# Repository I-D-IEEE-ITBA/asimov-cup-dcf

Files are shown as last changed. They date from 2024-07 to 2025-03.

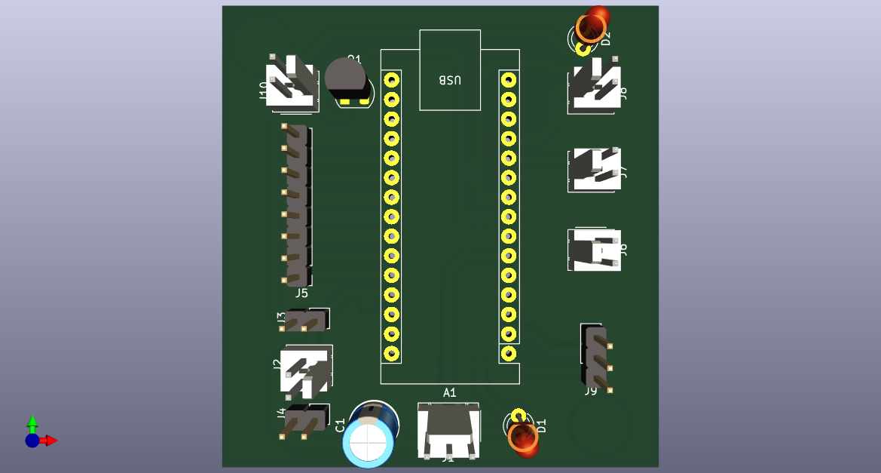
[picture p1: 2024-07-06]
docs/pcb_designs/controller/3d_top.png

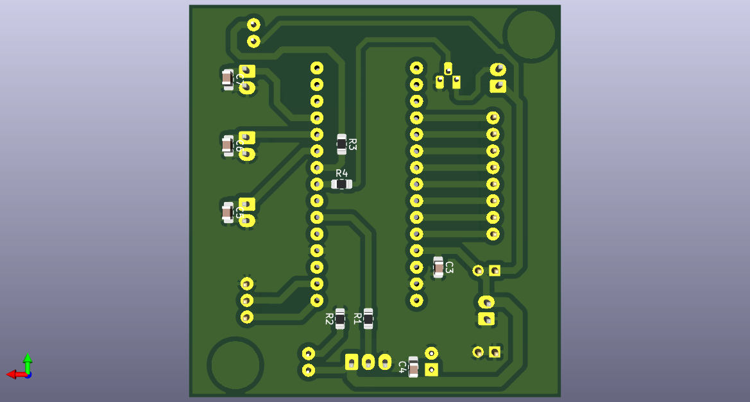
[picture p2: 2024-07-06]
docs/pcb_designs/controller/3d_bot.png

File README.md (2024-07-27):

# Display Contador Futbol (DCF)

## Descripción

Proyecto del *Display Contador Futbol*, que forma parte del desarrollo de la [Asimov Cup](https://ieeeitba.org.ar/asimovcup) en la competencia de *Futbol*.

DCF permite dar la señal de inicio del partido, cronometrar el tiempo de juego, pausarlo de ser necesario, a la vez que mantiene la cuenta de goles anotados por cada equipo.

El repositorio incluye tanto el hardware como el firmware desarrollado.

----------

<p align="middle">    
    ITBA Logo
    <a href="https://ieeeitba.org.ar/">IEEE ITBA Logo</a>
    IEEE Logo
</p>

<p align="middle">    
    <a href="https://github.com/IEEESBITBA">GitHub Repository</a>
    <a href="https://www.linkedin.com/company/ieee-itba/">LinkedIn Organization</a>
    <a href="https://www.instagram.com/ieee.itba/">Instagram Profile</a>
</p>

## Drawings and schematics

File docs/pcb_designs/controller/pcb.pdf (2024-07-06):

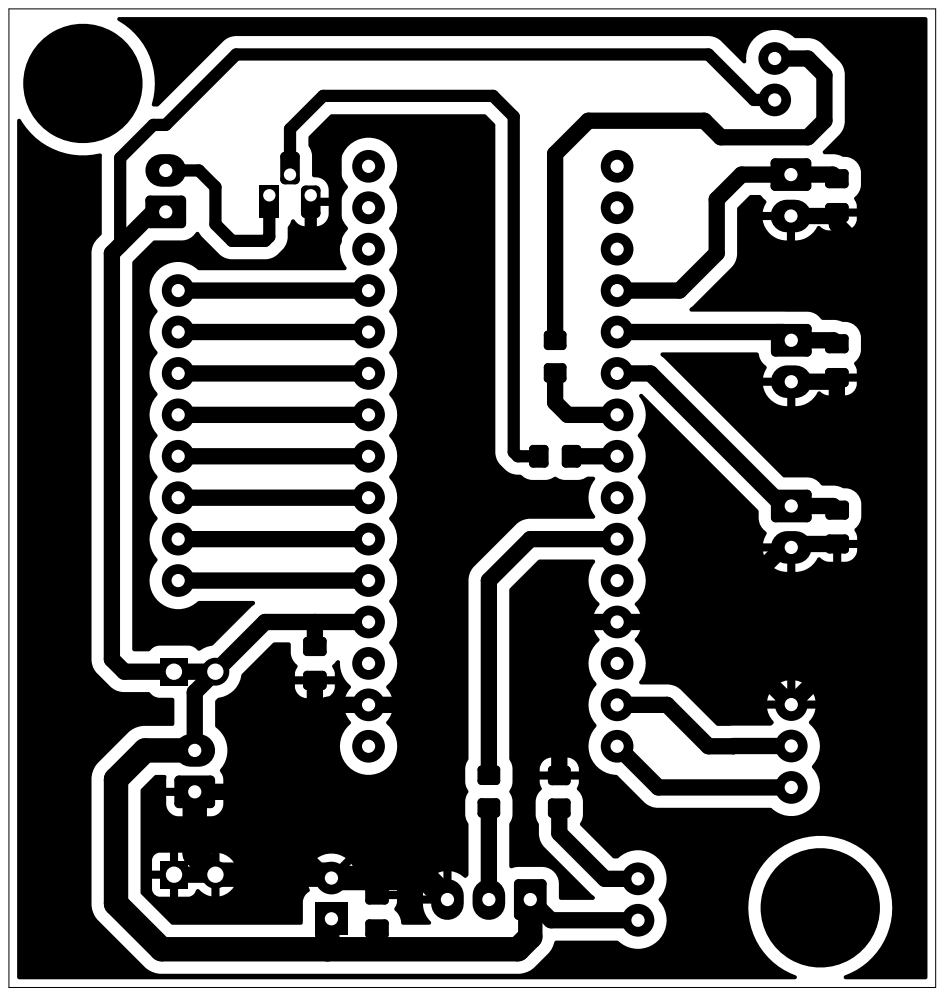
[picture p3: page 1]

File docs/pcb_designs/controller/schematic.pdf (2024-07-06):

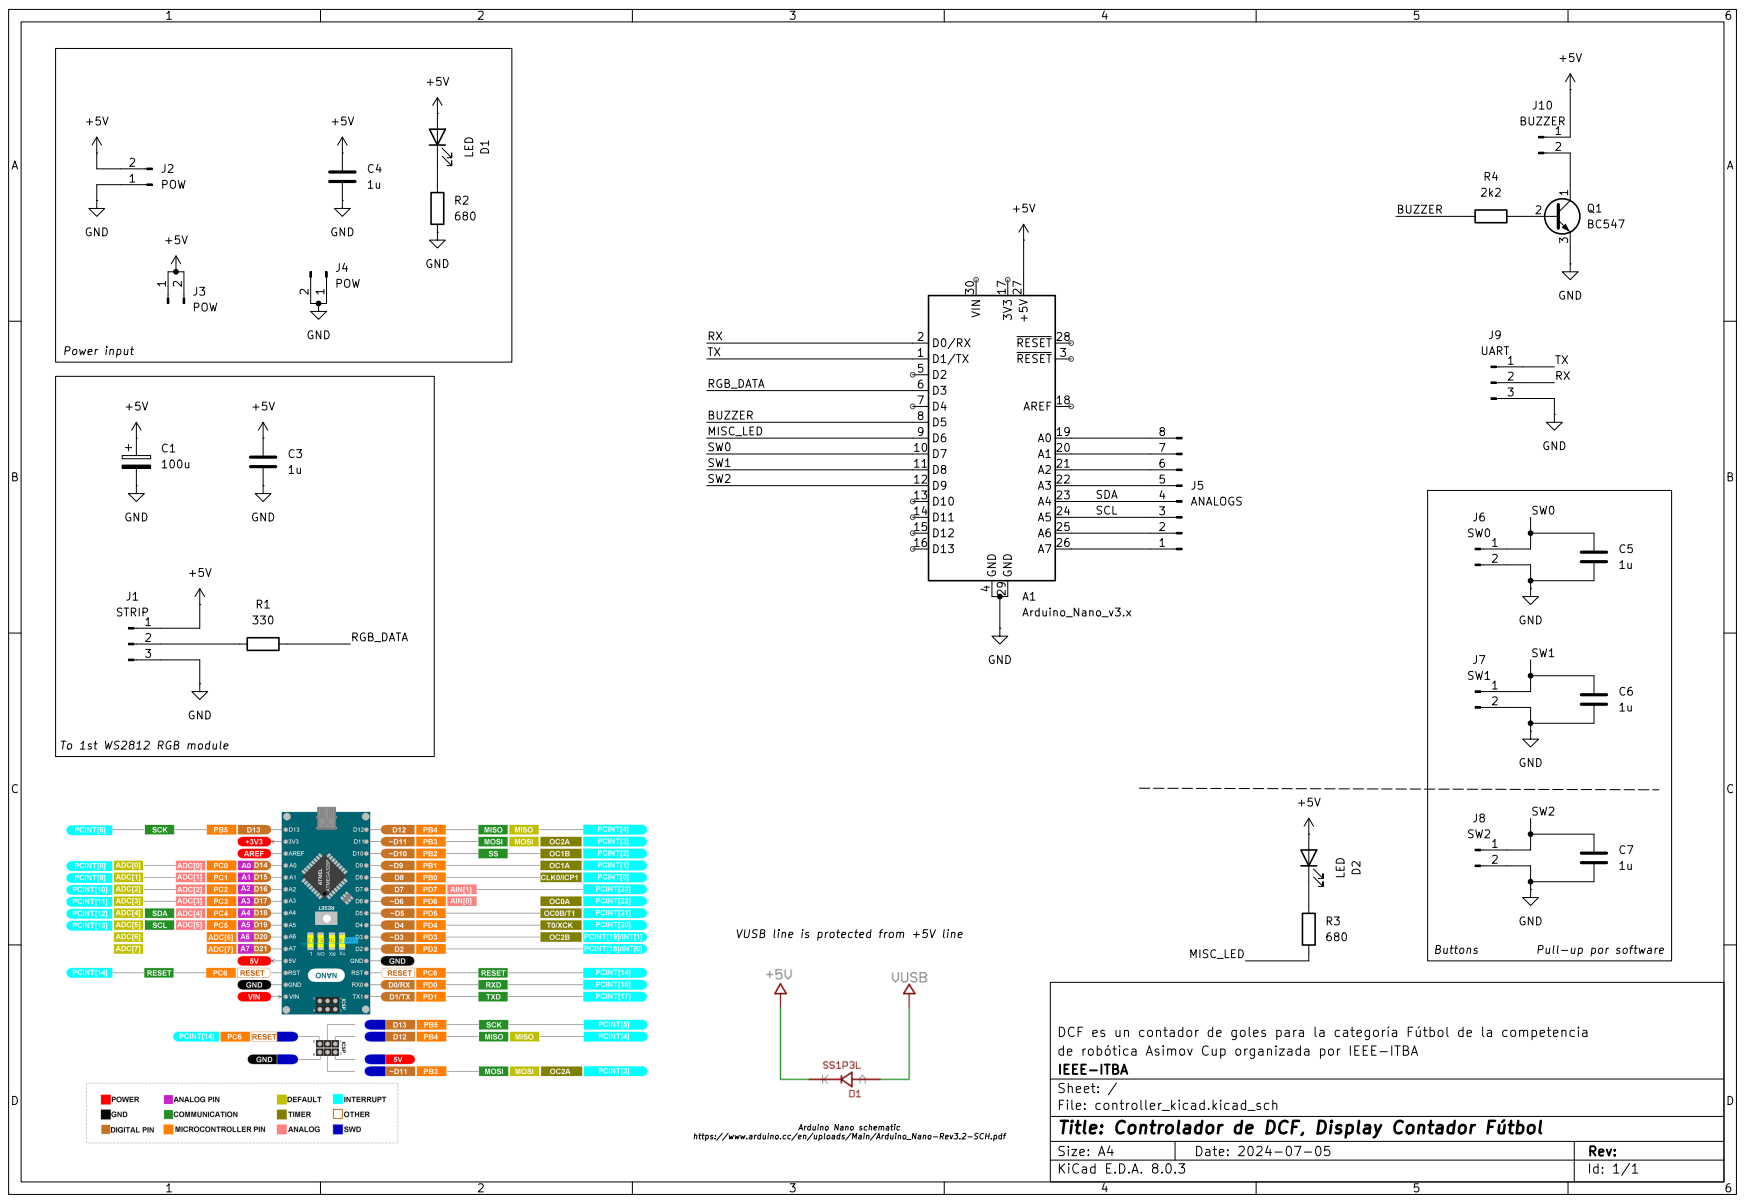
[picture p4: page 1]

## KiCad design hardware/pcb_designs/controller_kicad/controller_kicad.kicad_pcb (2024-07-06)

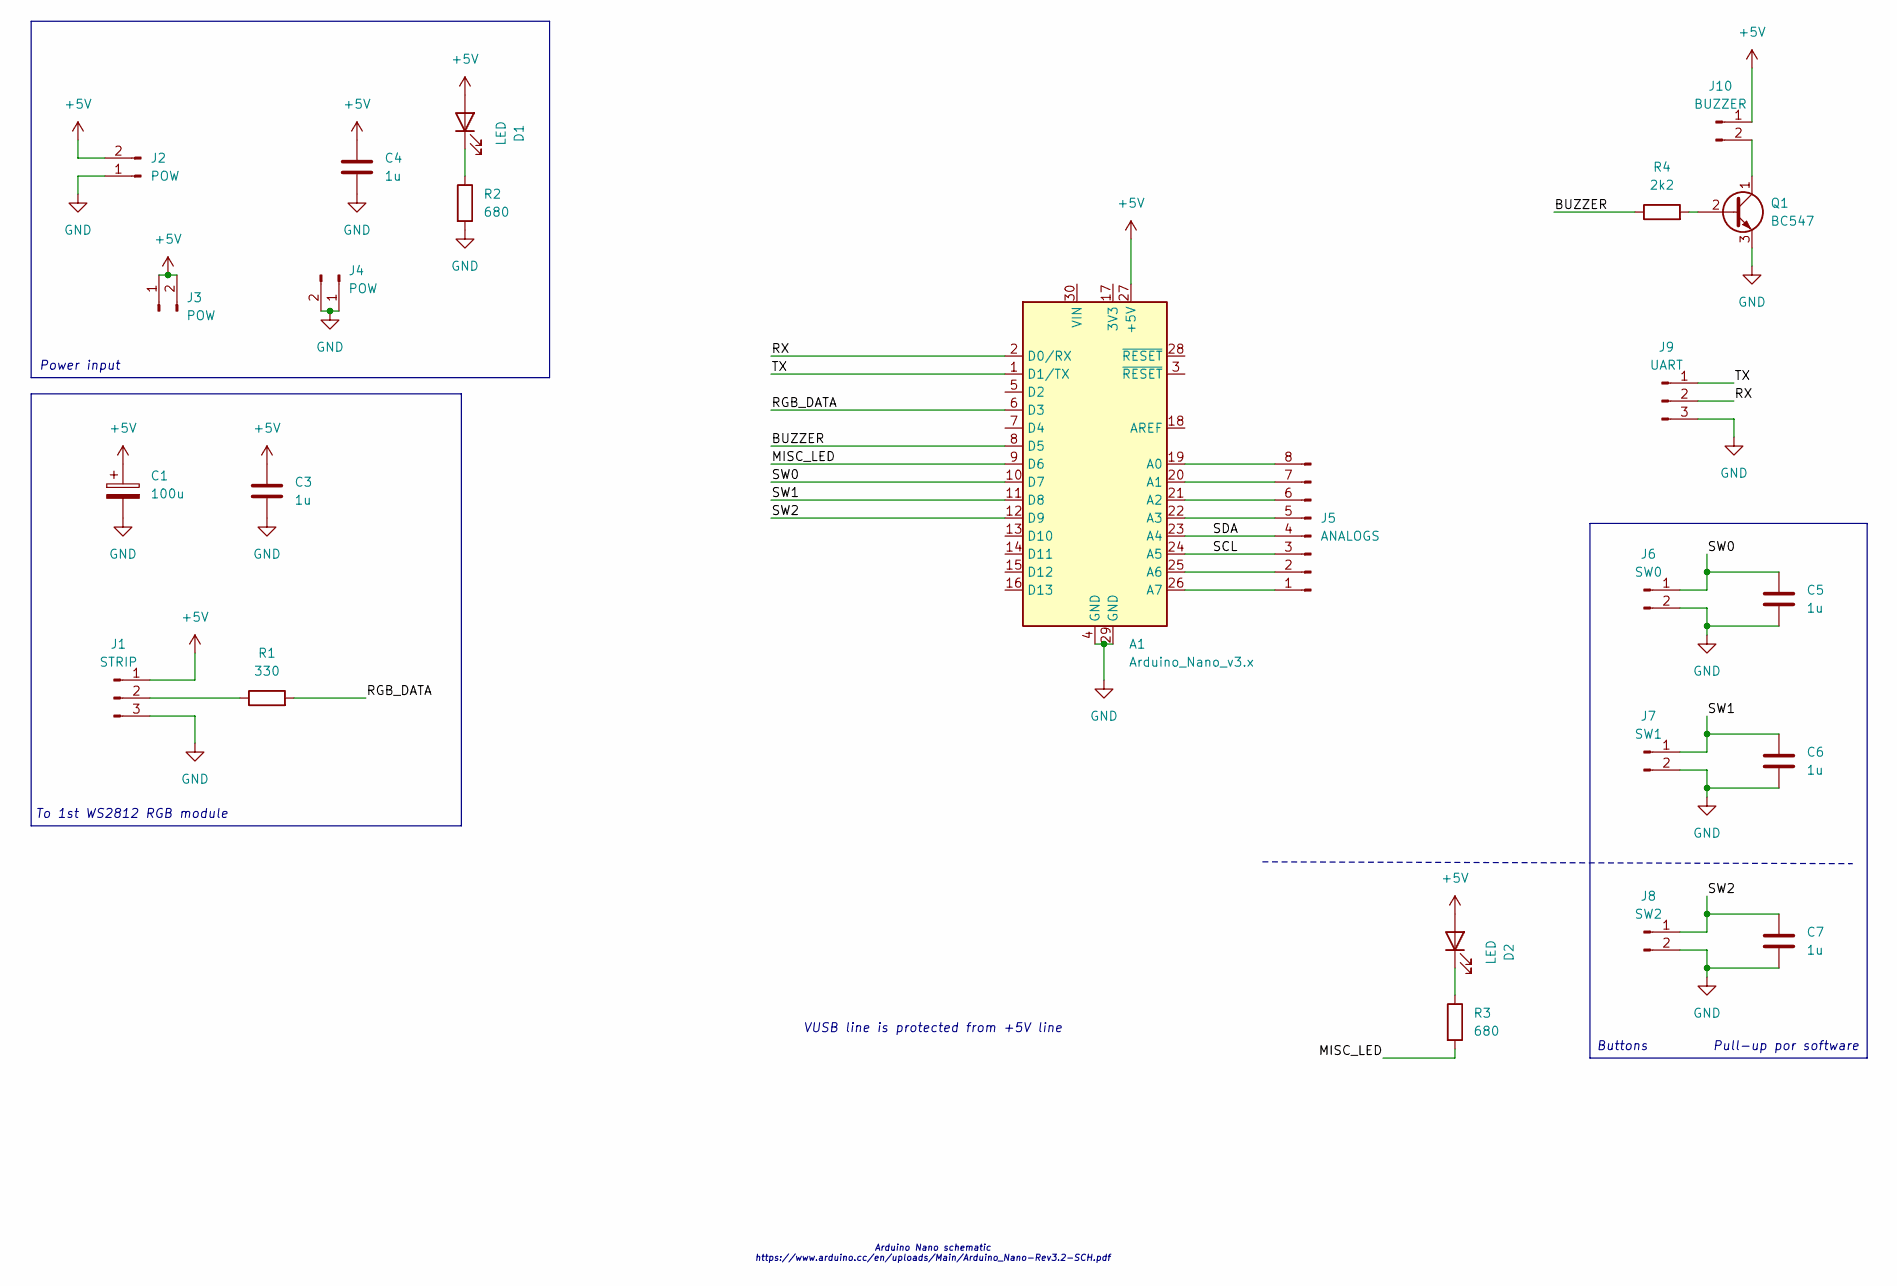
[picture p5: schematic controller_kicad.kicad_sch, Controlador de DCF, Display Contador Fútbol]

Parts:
A1: Arduino_Nano_v3.x; Arduino_Nano
C1: 100u; CP_Radial_D6.3mm_P2.50mm
C3, C4, C5, C6, C7: 1u; C_0805_2012Metric_Pad1.18x1.45mm_HandSolder
D1, D2: LED; LED_D3.0mm
J1: STRIP; Molex_KK-254_AE-6410-03A_1x03_P2.54mm_Vertical
J2: POW; Molex_KK-254_AE-6410-02A_1x02_P2.54mm_Vertical
J3, J4: POW; PinHeader_1x02_P2.54mm_Vertical
J5: ANALOGS; PinHeader_1x08_P2.54mm_Vertical
J6: SW0; Molex_KK-254_AE-6410-02A_1x02_P2.54mm_Vertical
J7: SW1; Molex_KK-254_AE-6410-02A_1x02_P2.54mm_Vertical
J8: SW2; Molex_KK-254_AE-6410-02A_1x02_P2.54mm_Vertical
J9: UART; PinHeader_1x03_P2.54mm_Vertical
J10: BUZZER; Molex_KK-254_AE-6410-02A_1x02_P2.54mm_Vertical
Q1: BC547; TO-92_HandSolder
R1: 330; R_0805_2012Metric_Pad1.20x1.40mm_HandSolder
R2, R3: 680; R_0805_2012Metric_Pad1.20x1.40mm_HandSolder
R4: 2k2; R_0805_2012Metric_Pad1.20x1.40mm_HandSolder

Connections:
+5V: A1.27 (+5V), C1.1, C3.1, C4.1, D1.2 (A), D2.2 (A), J1.1, J2.2, J3.1, J3.2, J10.1
/BUZZER: A1.8 (D5), R4.1
/MISC_LED: A1.9 (D6), R3.2
/RGB_DATA: A1.6 (D3), R1.2
/RX: A1.2 (D0/RX), J9.2
/SCL: A1.24 (A5), J5.3
/SDA: A1.23 (A4), J5.4
/SW0: A1.10 (D7), C5.1, J6.1
/SW1: A1.11 (D8), C6.1, J7.1
/SW2: A1.12 (D9), C7.1, J8.1
/TX: A1.1 (D1/TX), J9.1
GND: A1.4 (GND), A1.29 (GND), C1.2, C3.2, C4.2, C5.2, C6.2, C7.2, J1.3, J2.1, J4.1, J4.2, J6.2, J7.2, J8.2, J9.3, Q1.3 (E), R2.2
unnamed: A1.19 (A0), J5.8
unnamed: A1.20 (A1), J5.7
unnamed: A1.21 (A2), J5.6
unnamed: A1.22 (A3), J5.5
unnamed: A1.25 (A6), J5.2
unnamed: A1.26 (A7), J5.1
unnamed: D1.1 (K), R2.1
unnamed: D2.1 (K), R3.1
unnamed: J1.2, R1.1
unnamed: J10.2, Q1.1 (C)
unnamed: Q1.2 (B), R4.2

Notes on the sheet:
Pull-up por software
Arduino Nano schematic https://www.arduino.cc/en/uploads/Main/Arduino_Nano-Rev3.2-SCH.pdf
Power input
To 1st WS2812 RGB module
VUSB line is protected from +5V line
Buttons

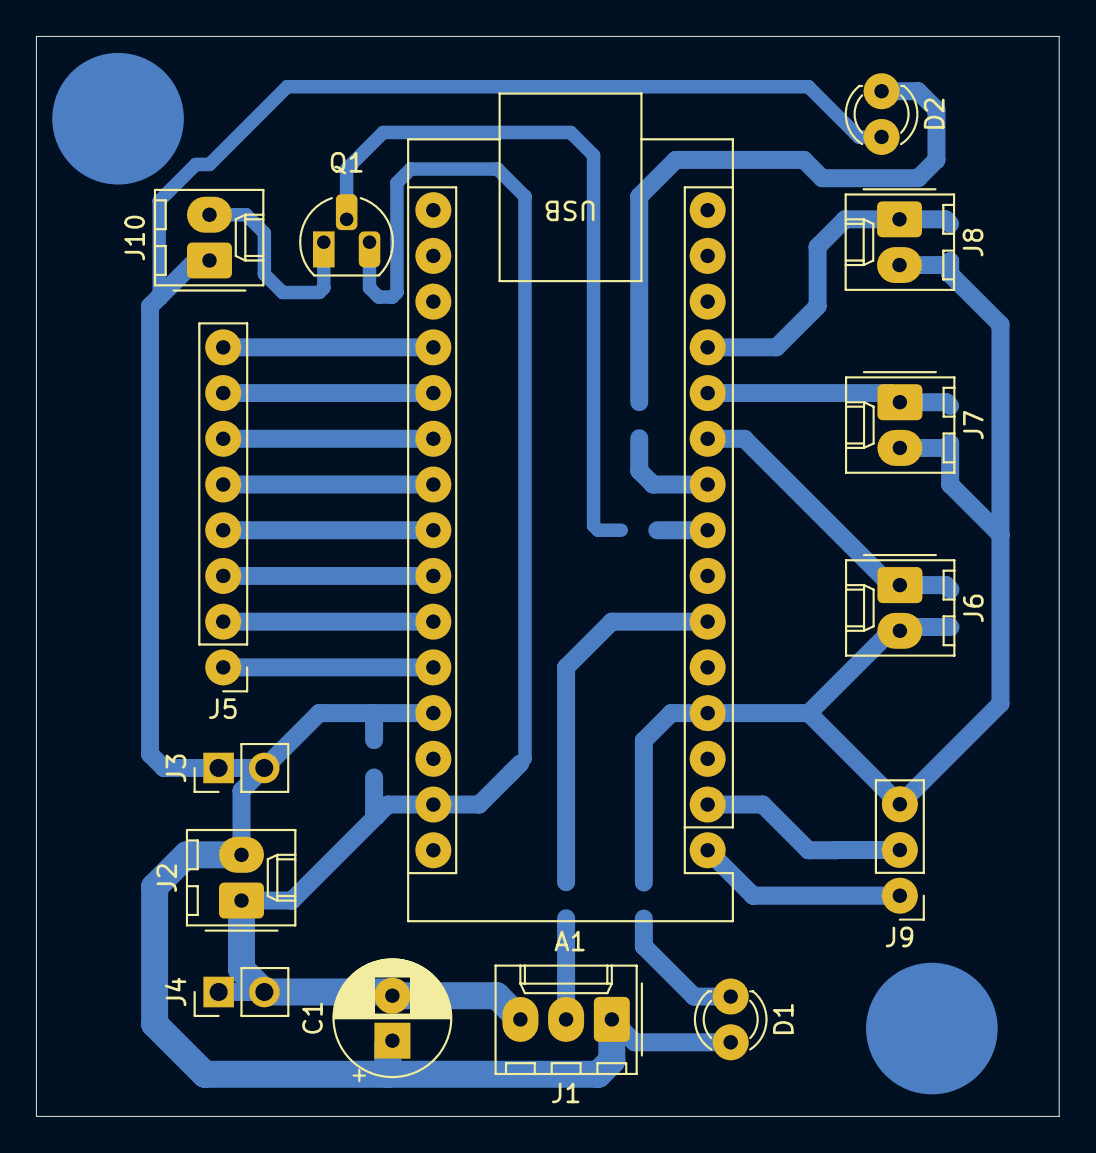
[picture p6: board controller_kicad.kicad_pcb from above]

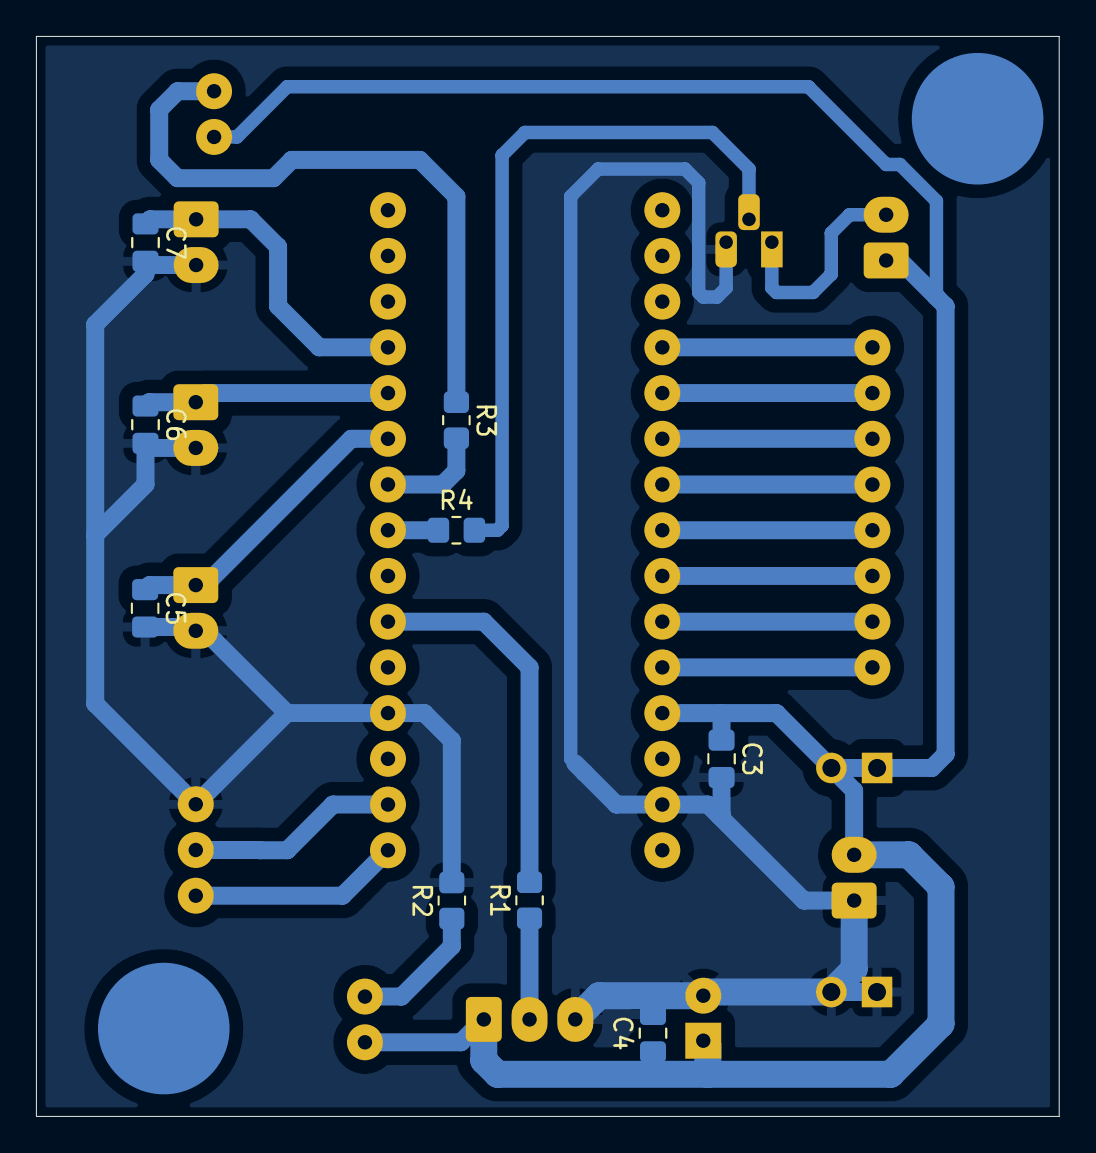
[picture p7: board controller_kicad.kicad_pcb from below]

Board: 2 copper layers, 56.8 x 60.0 mm, 24 parts (9 on the bottom side), 23 nets.

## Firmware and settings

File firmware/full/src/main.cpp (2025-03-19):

/**
 * @file main.cpp
 * @brief Este archivo contiene el código principal del firmware para el proyecto Asimov Cup DCF.
 *
 * El firmware controla la funcionalidad de los botones, los displays de 7 segmentos y los LEDs RGB.
 * Los botones permiten incrementar o decrementar contadores, mientras que los displays muestran los valores actuales.
 * Los LEDs RGB se utilizan para mostrar dígitos en los displays.
 *
 * @author IEEE-ITBA | I+D | Santi Lopez - Ale Heir - Joaco Torino
 * @date 2024-07
 */

#include <Arduino.h>
#include <FastLED.h>
#include <string.h>

// Definiciones de depuración
#define DEBUG

#ifdef DEBUG
#ifndef BAUD_RATE
#define BAUD_RATE 115200
#endif // !BAUD_RATE
#define DEBUG_PRINT(x) Serial.print(x)
#define DEBUG_PRINTLN(x) Serial.println(x)
#else
#define DEBUG_PRINT(x)
#define DEBUG_PRINTLN(x)
#endif // DEBUG

// Definiciones de pines
#define PIN_RGB_DATA 3
#define PIN_BUZZER 5
#define PIN_SW0 7
#define PIN_SW1 8
#define PIN_SW2 9
#define PIN_LED_BUILTIN LED_BUILTIN
#define PIN_MISC_LED 6

// Definiciones de botones
#define BUTTON_P1 PIN_SW0
#define BUTTON_P2 PIN_SW1
#define BUTTON_PRESSED LOW

// Definiciones de LEDs
#define NUM_LEDS 56 // 14 LEDs por dígito, 2 displays por lado, 2 lados
#define DEFAULT_BRIGTHNESS 100

// Definiciones de tiempos
#define DEBOUNCE_DELAY_MS 50
#define LONG_PRESS_DELAY_MS 600
#define BOTH_PRESS_WINDOW_MS 500 // Ventana de tiempo para detectar ambos botones presionados
#define UPDATE_RATE 50

// Definiciones de audio
#define SHORT_PRESS_PWM 160
#define LONG_PRESS_PWM 250
#define DOUBLE_PRESS_PWM 255

#define SHORT_PRESS_SFX_DURATION 150
#define LONG_PRESS_SFX_DURATION 250
#define DOUBLE_PRESS_SFX_DURATION 750

// Enumeración de eventos de botones
enum ButtonEvents
{
    NONE,
    SHORT_PRESS_P1,
    SHORT_PRESS_P2,
    LONG_PRESS_P1,
    LONG_PRESS_P2,
    BOTH_LONG_PRESS
};

// Declaraciones de funciones -------------------------------------------------

// Actualiza los displays de 7 segmentos con los valores actuales
void updateDisplays();

// Procesa el estado de los botones y devuelve el evento correspondiente
ButtonEvents processButtons();

// Muestra un número en los displays de 7 segmentos
bool showNumber(int number, bool isLeft);

// Muestra un dígito en una posición específica del array de LEDs
bool showDigit(int digit, int startIdx, CRGB color = CRGB::BlueViolet);

// ------------------------------------------------- Declaraciones de funciones

// Variables globales
CRGB leds[NUM_LEDS];
int count_p1 = 0;
int count_p2 = 0;

void setup()
{
#ifdef DEBUG
    Serial.begin(BAUD_RATE);
#endif

    // Inicialización de los módulos RGB
    FastLED.addLeds<WS2812B, PIN_RGB_DATA, GRB>(leds, NUM_LEDS).setCorrection(TypicalLEDStrip);
    FastLED.setBrightness(DEFAULT_BRIGTHNESS);

    // Configuración de los pines de los botones como entradas
    pinMode(PIN_SW0, INPUT_PULLUP);
    pinMode(PIN_SW1, INPUT_PULLUP);
    pinMode(PIN_SW2, INPUT_PULLUP);

    // Configuración de otros pines
    digitalWrite(PIN_MISC_LED, HIGH);
    digitalWrite(PIN_LED_BUILTIN, LOW);
    pinMode(PIN_BUZZER, OUTPUT);
    pinMode(PIN_MISC_LED, OUTPUT);
    pinMode(PIN_LED_BUILTIN, OUTPUT);

    delay(10);

    CRGB temp[NUM_LEDS];
    memset(temp, CRGB::Black, sizeof(temp));
    memcpy(leds, temp, sizeof(leds));
    FastLED.show();
    
    delay(10);

    updateDisplays();

    delay(10);
}

class SoundManager
{
public:
    static void Tick()
    {
        auto& manager = Get_();

        if (!manager.playing)
            return;
        
        if ((millis() - manager.start_ms) > manager.duration_ms)
        {
            manager.playing = false;
            manager.start_ms = 0;
            manager.pwmIntensity = 0;
            manager.duration_ms = 0;
            analogWrite(PIN_BUZZER, 0);
        }   
    }
    static void Play(const unsigned int pwmIntensity_, const unsigned long long duration_ms_)
    {
        auto& manager = Get_();

        manager.playing = true;
        manager.duration_ms = duration_ms_;
        manager.pwmIntensity = pwmIntensity_;
        manager.start_ms = millis();
        analogWrite(PIN_BUZZER, pwmIntensity_); 
    }
private:
    static SoundManager& Get_()
    {
        static SoundManager singleton;
        return singleton;
    }
    SoundManager() = default;

    // state
    bool playing = false;
    unsigned int pwmIntensity = 0;
    unsigned long long duration_ms = 0;
    unsigned long long start_ms = 0;
};

void loop()
{
    ButtonEvents event = processButtons();

    SoundManager::Tick();

    switch (event)
    {
    case SHORT_PRESS_P1:
        DEBUG_PRINTLN("Pulsación corta en P1");
        count_p1++;
        count_p1 = (count_p1 > 99) ? 99 : count_p1;
        SoundManager::Play(SHORT_PRESS_PWM, SHORT_PRESS_SFX_DURATION);
        break;

    case LONG_PRESS_P1:
        DEBUG_PRINTLN("Pulsación larga en P1");
        count_p1--;
        count_p1 = (count_p1 < 0) ? 0 : count_p1;
        SoundManager::Play(LONG_PRESS_PWM, LONG_PRESS_SFX_DURATION);
        break;

    case SHORT_PRESS_P2:
        DEBUG_PRINTLN("Pulsación corta en P2");
        count_p2++;
        count_p2 = (count_p2 > 99) ? 99 : count_p2;
        SoundManager::Play(SHORT_PRESS_PWM, SHORT_PRESS_SFX_DURATION);
        break;

    case LONG_PRESS_P2:
        DEBUG_PRINTLN("Pulsación larga en P2");
        count_p2--;
        count_p2 = (count_p2 < 0) ? 0 : count_p2;
        SoundManager::Play(LONG_PRESS_PWM, LONG_PRESS_SFX_DURATION);
        break;

    case BOTH_LONG_PRESS:
        DEBUG_PRINTLN("Ambos botones presionados por mucho tiempo");
        count_p1 = 0;
        count_p2 = 0;
        SoundManager::Play(DOUBLE_PRESS_PWM, DOUBLE_PRESS_SFX_DURATION);
        break;

    default:
        break;
    }

    if (event != NONE)
    {
        DEBUG_PRINT("Contador P1: ");
        DEBUG_PRINT(count_p1);
        DEBUG_PRINT(" | Contador P2: ");
        DEBUG_PRINTLN(count_p2);

        updateDisplays();
    }
}

void updateDisplays()
{
    showNumber(count_p1, true);
    showNumber(count_p2, false);
}

ButtonEvents processButtons()
{
    static unsigned long lastDebounceTime_p1 = 0;
    static unsigned long lastDebounceTime_p2 = 0;
    static unsigned long pressStartTime_p1 = 0;
    static unsigned long pressStartTime_p2 = 0;
    static bool buttonPressed_p1 = false;
    static bool buttonPressed_p2 = false;
    static bool reading_p1 = !BUTTON_PRESSED;
    static bool reading_p2 = !BUTTON_PRESSED;
    static bool previous_reading_p1 = !BUTTON_PRESSED;
    static bool previous_reading_p2 = !BUTTON_PRESSED;

    bool current_reading_p1 = digitalRead(BUTTON_P1);
    bool current_reading_p2 = digitalRead(BUTTON_P2);

    // sleep interval to allow proper press detection
    delay(UPDATE_RATE);

    // Check P1 short press
    if (current_reading_p1 != previous_reading_p1 && millis() - lastDebounceTime_p1 > DEBOUNCE_DELAY_MS)
    {
        lastDebounceTime_p1 = millis();
        reading_p1 = current_reading_p1;

        if (reading_p1 == BUTTON_PRESSED)
        {
            pressStartTime_p1 = millis(); // start counting time
            buttonPressed_p1 = true;
        }
        else // was short press!
        {
            buttonPressed_p1 = false;
            previous_reading_p1 = current_reading_p1;

            if (millis() - pressStartTime_p1 < LONG_PRESS_DELAY_MS)
            {
                return SHORT_PRESS_P1;
            }
        }
    }

    // Check P2 short press
    if (current_reading_p2 != previous_reading_p2 && millis() - lastDebounceTime_p2 > DEBOUNCE_DELAY_MS)
    {
        lastDebounceTime_p2 = millis();
        reading_p2 = current_reading_p2;

        if (reading_p2 == BUTTON_PRESSED)
        {
            pressStartTime_p2 = millis(); // start counting time
            buttonPressed_p2 = true;
        }
        else // was short press!
        {
            buttonPressed_p2 = false;
            previous_reading_p2 = current_reading_p2;

            if (millis() - pressStartTime_p2 < LONG_PRESS_DELAY_MS)
            {
                return SHORT_PRESS_P2;
            }
        }
    }

    // Check both buttons long press
    if (buttonPressed_p1 && buttonPressed_p2 &&
        (abs(pressStartTime_p1 - pressStartTime_p2) < BOTH_PRESS_WINDOW_MS) &&
        (millis() - pressStartTime_p1) > LONG_PRESS_DELAY_MS &&
        (millis() - pressStartTime_p2) > LONG_PRESS_DELAY_MS)
    {
        buttonPressed_p1 = false;
        buttonPressed_p2 = false;
        return BOTH_LONG_PRESS;
    }

    // Check P1 long press
    if (buttonPressed_p1 && !buttonPressed_p2 && ((millis() - pressStartTime_p1) > LONG_PRESS_DELAY_MS))
    {
        buttonPressed_p1 = false;
        return LONG_PRESS_P1;
    }

    // Check P2 long press
    if (buttonPressed_p2 && !buttonPressed_p1 && ((millis() - pressStartTime_p2) > LONG_PRESS_DELAY_MS))
    {
        buttonPressed_p2 = false;
        return LONG_PRESS_P2;
    }

    previous_reading_p1 = current_reading_p1;
    previous_reading_p2 = current_reading_p2;

    return NONE;
}

bool showNumber(int number, bool isLeft)
{
    if (number < 0 || number > 99)
    {
        return false;
    }

    int digit1 = number / 10; // Dígito de las decenas
    int digit2 = number % 10; // Dígito de las unidades

    // La logica esta pensada para que el orden de los numeros sea 
    // [ 4 , 3 , 2 , 1 ]
    // Para utilizar el codigo con orden de los numeros
    // [ 1 , 2 , 3 , 4 ]
    // Se debe cambiar el startIdx de isLeft en -28 y del else en +28. Ademas, se debe intercambiar el orden de digit1
    // y digit2 en ambos caminos

    if (isLeft)
    {
        showDigit(digit2, 28, CRGB::OrangeRed);  // Mostrar el primer dígito en el primer display del lado izquierdo
        showDigit(digit1, 42, CRGB::OrangeRed); // Mostrar el segundo dígito en el segundo display del lado izquierdo
    }
    else
    {
        showDigit(digit2, 0, CRGB::BlueViolet); // Mostrar el primer dígito en el primer display del lado derecho
        showDigit(digit1, 14, CRGB::BlueViolet); // Mostrar el segundo dígito en el segundo display del lado derecho
    }

    return true;
}

bool showDigit(int digit, int startIdx, CRGB color)
{
    // El arreglo segmentMap mapea los numeros si el orden de los leds es el siguiente:
    //  _ [ 1 ]_
    // |6|    |2|
    // |_|    |_|
    //  _ [ 7 ]_
    // |5|    |3|
    // |_|    |_|
    //    [ 4 ]


    static const uint8_t segmentMap[] = {
        B11111100, // 0
        B01100000, // 1
        B11011010, // 2
        B11110010, // 3
        B01100110, // 4
        B10110110, // 5
        B11111010, // 6
        B11100000, // 7
        B11111110, // 8
        B11100110  // 9
    };

    // El arreglo segmentMap mapea los numeros si el orden de los leds es el siguiente:
    //  _ [ 4 ]_
    // |3|    |5|
    // |_|    |_|
    //  _ [ 7 ]_
    // |2|    |6|
    // |_|    |_|
    //    [ 1 ]

    static uint8_t segmentMapFlipped[] = {
        B11111100, // 0
        B00001100, // 1
        B11011010, // 2
        B10011110, // 3
        B00101110, // 4
        B10110110, // 5
        B11110110, // 6
        B00011100, // 7
        B11111110, // 8
        B00111110  // 9
    };

    if (digit < 0 || digit > 9 || startIdx < 0 || startIdx >= NUM_LEDS)
    {
        return false;
    }

    uint8_t mask = B10000000;
    for (int i = 0; i < 7; i++)
    {
        // Reemplazar en esta linea de codigo por el arreglo que represente la orientacion correspondiente de los digitos
        if (segmentMapFlipped[digit] & mask)
        {
            leds[startIdx + i * 2] = color;
            leds[startIdx + i * 2 + 1] = color;
        }
        else
        {
            leds[startIdx + i * 2] = CRGB::Black;
            leds[startIdx + i * 2 + 1] = CRGB::Black;
        }

        mask >>= 1;
    }

    FastLED.show();

    return true;
}

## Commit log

2024-07-05 starting controller PCB, preparing directories
    [controller_kicad.kicad_pcb, controller_kicad.kicad_sch]
2024-07-06 controller PCB finished
    [controller_kicad.kicad_pcb, controller_kicad.kicad_sch]
2024-07-27 add elemental full firmware w/ button interactions, w/o {buzzer, visual effects}
    [main.cpp]
2024-07-29 fix pin assignments, tweak processButtons, add debug info
    [main.cpp]
2024-07-29 Agregado un delay en el loop principal para mejorar la consistencia en la detección de pulsaciones
2024-08-02 Agregado el sound manager. Soporta los numeros al reves
